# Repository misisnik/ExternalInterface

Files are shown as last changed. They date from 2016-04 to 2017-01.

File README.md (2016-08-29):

External user irnterface with usb
===================================
Project tags:
  - MCP2210
  - Displat with "IST3020"
  - Joystick
  - Python library

Project tree:
- hw
  - board with buttons on the left side - KiCad files - schematics and pcb
  - board with buttons next to joystick - KiCad files - schematics and pcb
  - casing - FreeCad projects for casing this user interface (3D pronting)
- sw
  - Python 3.4 project lib

It contains:
- [SW lib.](https://github.com/misisnik/ExternalInterface/tree/master/sw)
- [HW board 1](https://github.com/misisnik/ExternalInterface/tree/master/hw/board_buttons_next_to_joystick)
- [HW board 2](https://github.com/misisnik/ExternalInterface/tree/master/hw/board_buttons_on_the_other_side)
- [HW 3D casing](https://github.com/misisnik/ExternalInterface/tree/master/hw/casing)

Installation
------------
	-Ubuntu and python 2.7
	---------------
			$ apt-get update
			$ apt-get install python-dev
			$ apt-get install cython
			$ apt-get install libusb-1.0.0 libusb-1.0.0-dev libudev-dev
			$ pip install hidapi

		install Pillow
			$ apt-get install libjpeg-dev
			$ pip3 install pillow

		-- display LIB
		git clone https://github.com/misisnik/ExternalInterface

	-Raspbian Jesee
	---------------
			$ apt-get update
			$ sudo apt-get install git python3.4 python3-dev

		install pip3 from git
			$ git clone https://github.com/pypa/pip
			$ cd pip
			$ python3.4 setup.py install
			$ cd ..
			$ rm -r pip

		install cython
			$ apt-get install cython3

		libusb
			$ apt-get install libusb-1.0.0 libusb-1.0.0-dev libudev-dev

		install cython-hidapi
			$ git clone https://github.com/gbishop/cython-hidapi.git
			$ cd cython-hidapi
			$ python3 setup.py build
			$ python3 setup.py install
			$ cd ..
			$ rm -r cython-hidapi

		install Pillow
			$ apt-get install libjpeg-dev
			$ pip3 install pillow

		-- display LIB
		git clone https://github.com/misisnik/ExternalInterface

Examples
---------------

-[Main example - introduction of display + snake game](https://github.com/misisnik/ExternalInterface/blob/master/sw/example.py)

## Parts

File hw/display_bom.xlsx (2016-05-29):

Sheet: List1
Value | Seller | Part. No | Price [USD] | PC
2,2uF/10V | Farnell | 2496923 | 0.027 | 4
1uF/10V | Farnell | 2496916 | 0.017 | 8
0,1uF/25V | Farnell | 2496833 | 0.009 | 1
10nF/25V | Farnell | 2496827 | 0.009 | 1
4,7nF/ | Farnell | 1759098 | 0.016 | 1
1800pF | Farnell | 2524826 | 0.010 | 1
2200pF | Farnell | 2496845 | 0.008 | 1
2700pF | Farnell | 2524833 | 0.011 | 1
3300pF | Farnell | 2496853 | 0.007 | 1
3900pF | Farnell | 2524841 | 0.010 | 1
L-1334SRT | Farnell | 2001642 | 0.150 | 1
24R | Farnell | 2447310 | 0.004 | 1
390R | Farnell | 2447353 | 0.004 | 4
22K | Farnell | 9330828 | 0.001 | 1
33K | Farnell | 9331034 | 0.002 | 2
3K | Farnell | 9330976 | 0.001 | 1
10K | Farnell | 9330399 | 0.001 | 8
3K9 | Farnell | 9331140 | 0.002 | 1
68K | Farnell | 9331468 | 0.002 | 1
0R | Farnell | 2447743RL | 0.004 | 1
68R | Farnell | 9331484 | 0.002 | 2
1M | Farnell | 9330410 | 0.001 | 1
12MHz rez. | Farnell | 2470356 | 0.391 | 1
MIC5504-3,3 | Farnell | 2510377 | 0.097 | 1
LM239 | Farnell | 1564355 | 0.114 | 1
CD4532 | Farnell | 1739798 | 0.521 | 1
NPIC6C596ADJ | Farnell | 2445195 | 1.115 | 1
NE555 | Farnell | 9589880 | 0.314 | 1
USB typ B | Farnell | 1097897 | 0.754 | 1
ABT-405-RC PIEZO | Farnell | 1300024 | 1.303 | 1
MCP2210 | TME | MCP2210-I/SO | 1.897 | 1
PB6149L-3 | TME | PB6149L-3 | 0.850 | 2
192x64 px display + conn | buydisplay.com | ERC19264SBS-1 | 9.145 | 1
PCB | easyeda.com | Hasl, FR-4, 47x152mm | 4.215 | 1
Joystick | Ebay.com |  | 1.054 | 1
 |  | Total USD | 22.070

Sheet: List2
freq | cap
261 | 3.943703631e-08
294 | 3.501043019e-08
329 | 3.128591634e-08
349 | 2.949302715e-08
392 | 2.625782264e-08
440 | 2.33933329e-08
493 | 2.087843099e-08

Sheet: List4
0.649 | 0.0273608769
0.414 | 0.01745362563
0.204 | 0.008600337268
0.221 | 0.00931703204
0.389 | 0.01639966273
3.561 | 0.1501264755
0.102 | 0.004300168634
0.095 | 0.004005059022
0.033 | 0.001391231029
0.036 | 0.001517706577
0.033 | 0.001391231029
0.033 | 0.001391231029
0.044 | 0.001854974705
0.044 | 0.001854974705
0.091 | 0.003836424958
0.041 | 0.001728499157
0.033 | 0.001391231029
9.276 | 0.3910623946
2.311 | 0.09742833052
2.705 | 0.1140387858
12.368 | 0.5214165261
26.448 | 1.115008432
7.454 | 0.3142495784
17.889 | 0.7541736931
30.92 | 1.303541315
45 | 1.897133221
20.16 | 0.849915683
217 | 9.148397976
100 | 4.215851602
25 | 1.053962901

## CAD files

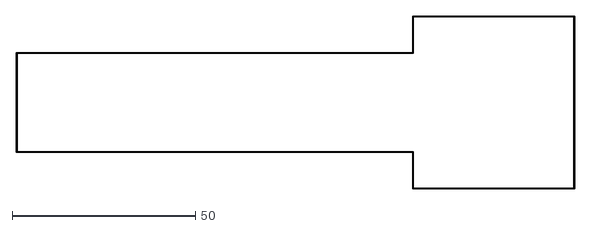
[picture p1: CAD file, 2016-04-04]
hw/board_buttons_on_the_other_side/rozhrani_semestralka-Edge_Cuts.dxf
152.1 x 47.1

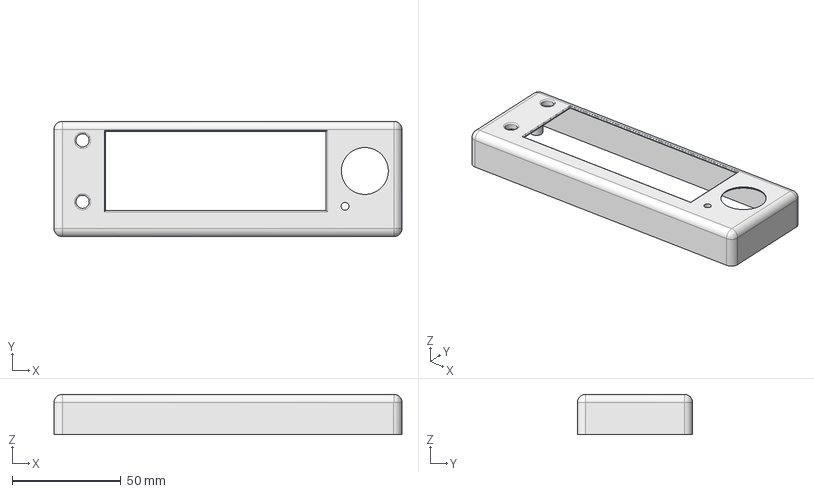
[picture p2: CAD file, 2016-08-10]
hw/casing 2/top_part.FCStd
160.0 x 53.0 x 18.5 mm

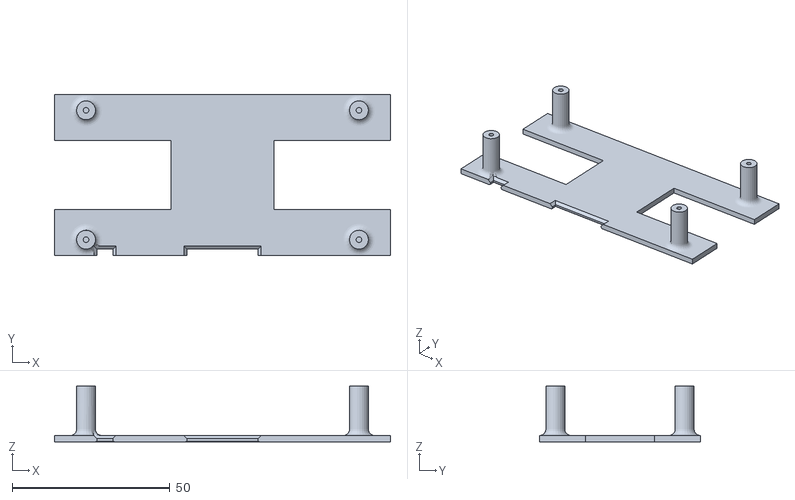
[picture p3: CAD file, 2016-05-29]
hw/casing/.stl format/table_part.stl
106.5 x 51.0 x 17.6

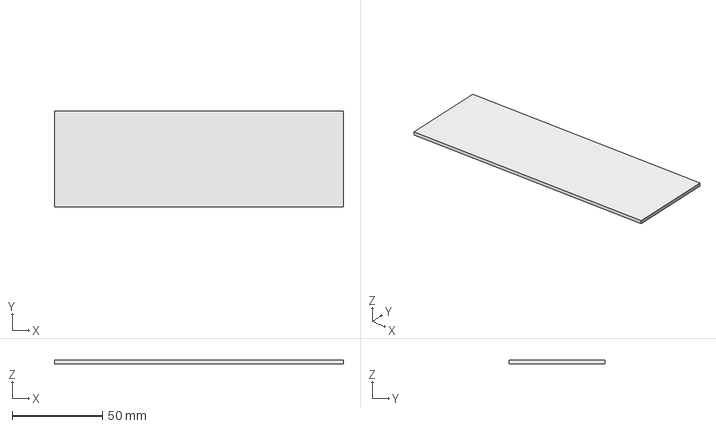
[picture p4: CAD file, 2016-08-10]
hw/casing 2/bottom_part.FCStd
160.0 x 53.0 x 2.00 mm

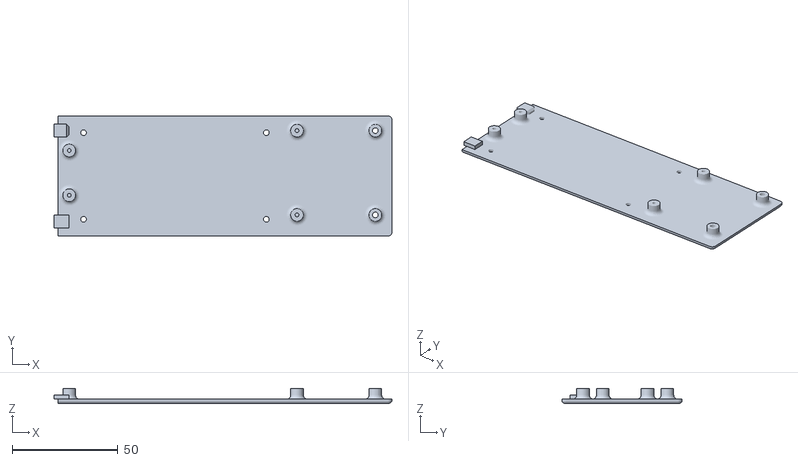
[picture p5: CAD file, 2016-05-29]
hw/casing/.stl format/bottom_part.stl
160.0 x 57.0 x 7.00

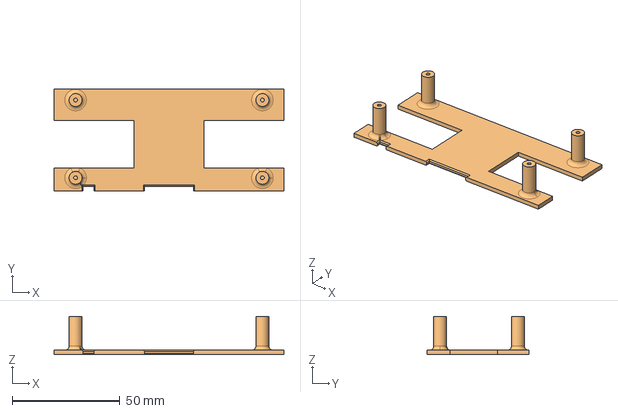
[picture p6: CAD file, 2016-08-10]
hw/casing 2/table_part.FCStd
106.5 x 47.0 x 17.6 mm
Fillet002 (Solid)

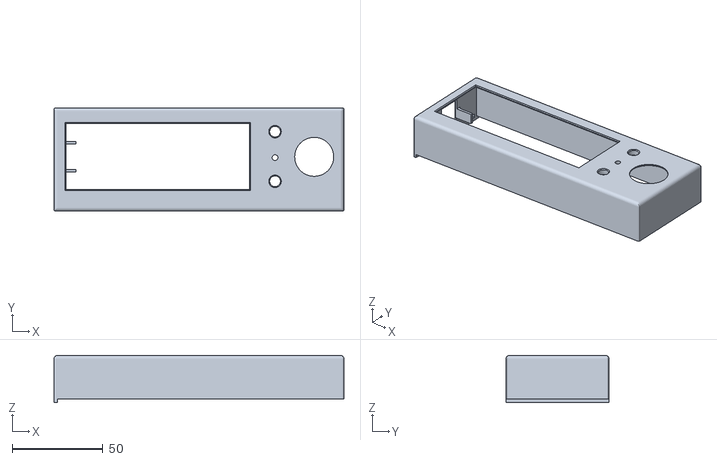
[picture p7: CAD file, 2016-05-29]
hw/casing/.stl format/top_part.stl
160.0 x 57.0 x 26.1

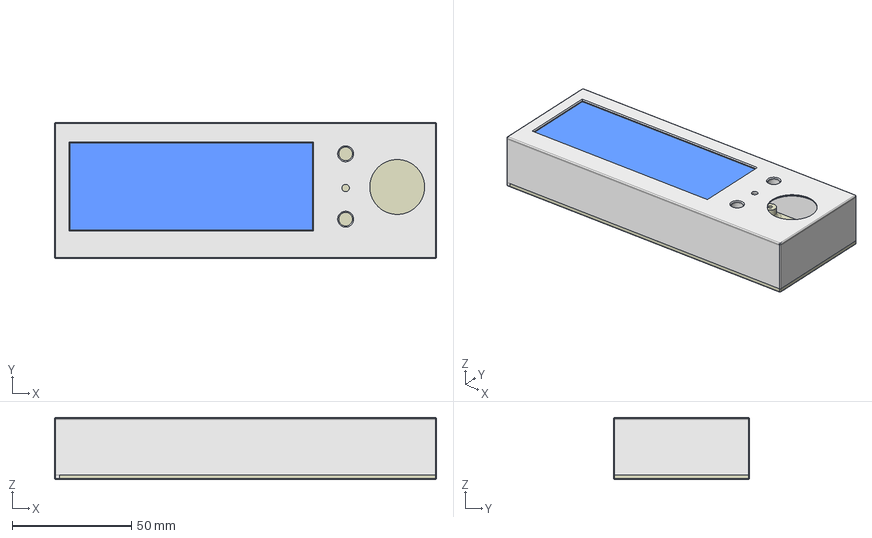
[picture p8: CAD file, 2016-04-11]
hw/casing/together.FCStd
160.0 x 57.0 x 26.1 mm
bottom
table
lcd
top

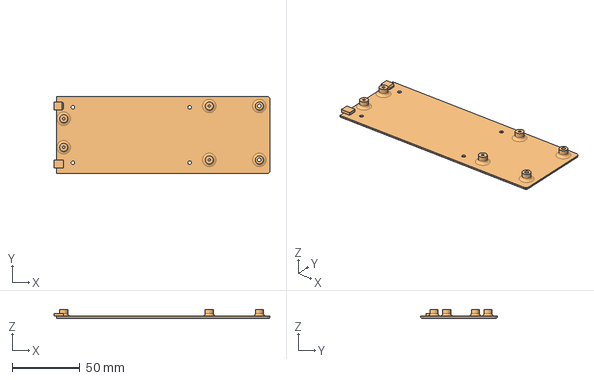
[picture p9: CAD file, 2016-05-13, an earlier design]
hw/casing/bottom_part.FCStd
160.0 x 57.0 x 7.00 mm
Fillet007 (Solid)

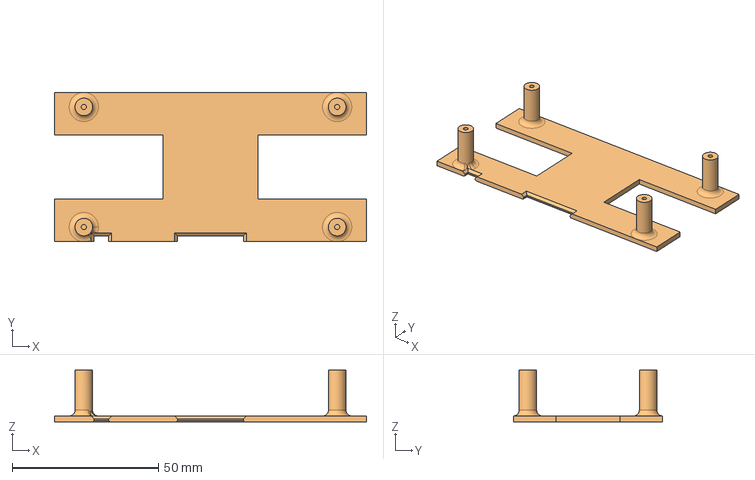
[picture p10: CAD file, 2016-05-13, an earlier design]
hw/casing/table_part.FCStd
106.5 x 51.0 x 17.6 mm
Fillet002 (Solid)

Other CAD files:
hw/casing/top_part.FCStd
hw/board_buttons_on_the_other_side/rozhrani_semestralka-F_Paste.dxf
hw/board_buttons_on_the_other_side/rozhrani_semestralka-F_SilkS.dxf

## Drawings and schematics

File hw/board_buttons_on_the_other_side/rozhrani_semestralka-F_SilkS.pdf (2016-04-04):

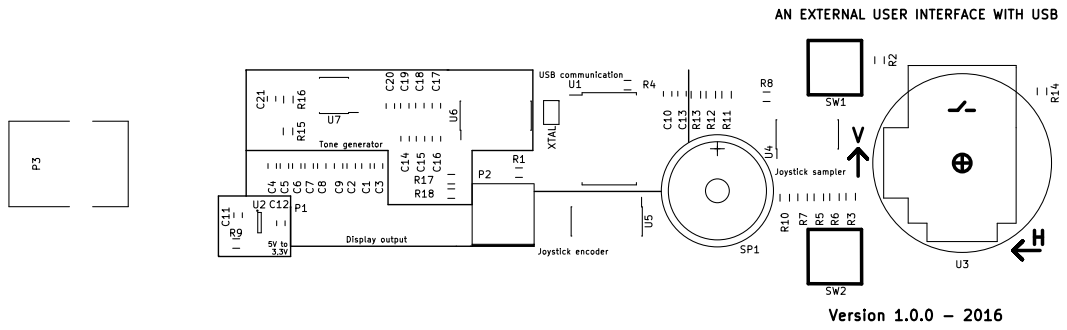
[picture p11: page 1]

Joystick encoder USB communication

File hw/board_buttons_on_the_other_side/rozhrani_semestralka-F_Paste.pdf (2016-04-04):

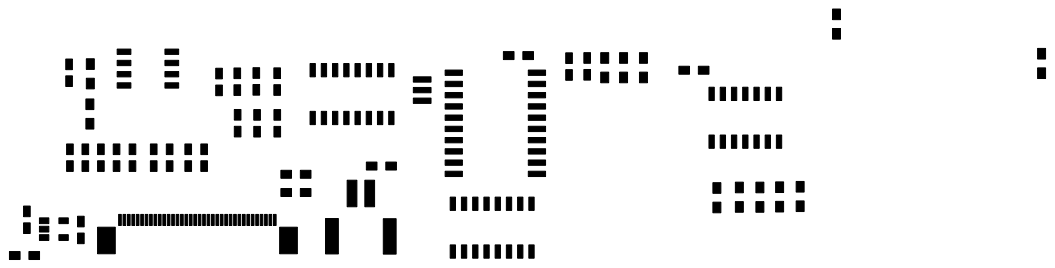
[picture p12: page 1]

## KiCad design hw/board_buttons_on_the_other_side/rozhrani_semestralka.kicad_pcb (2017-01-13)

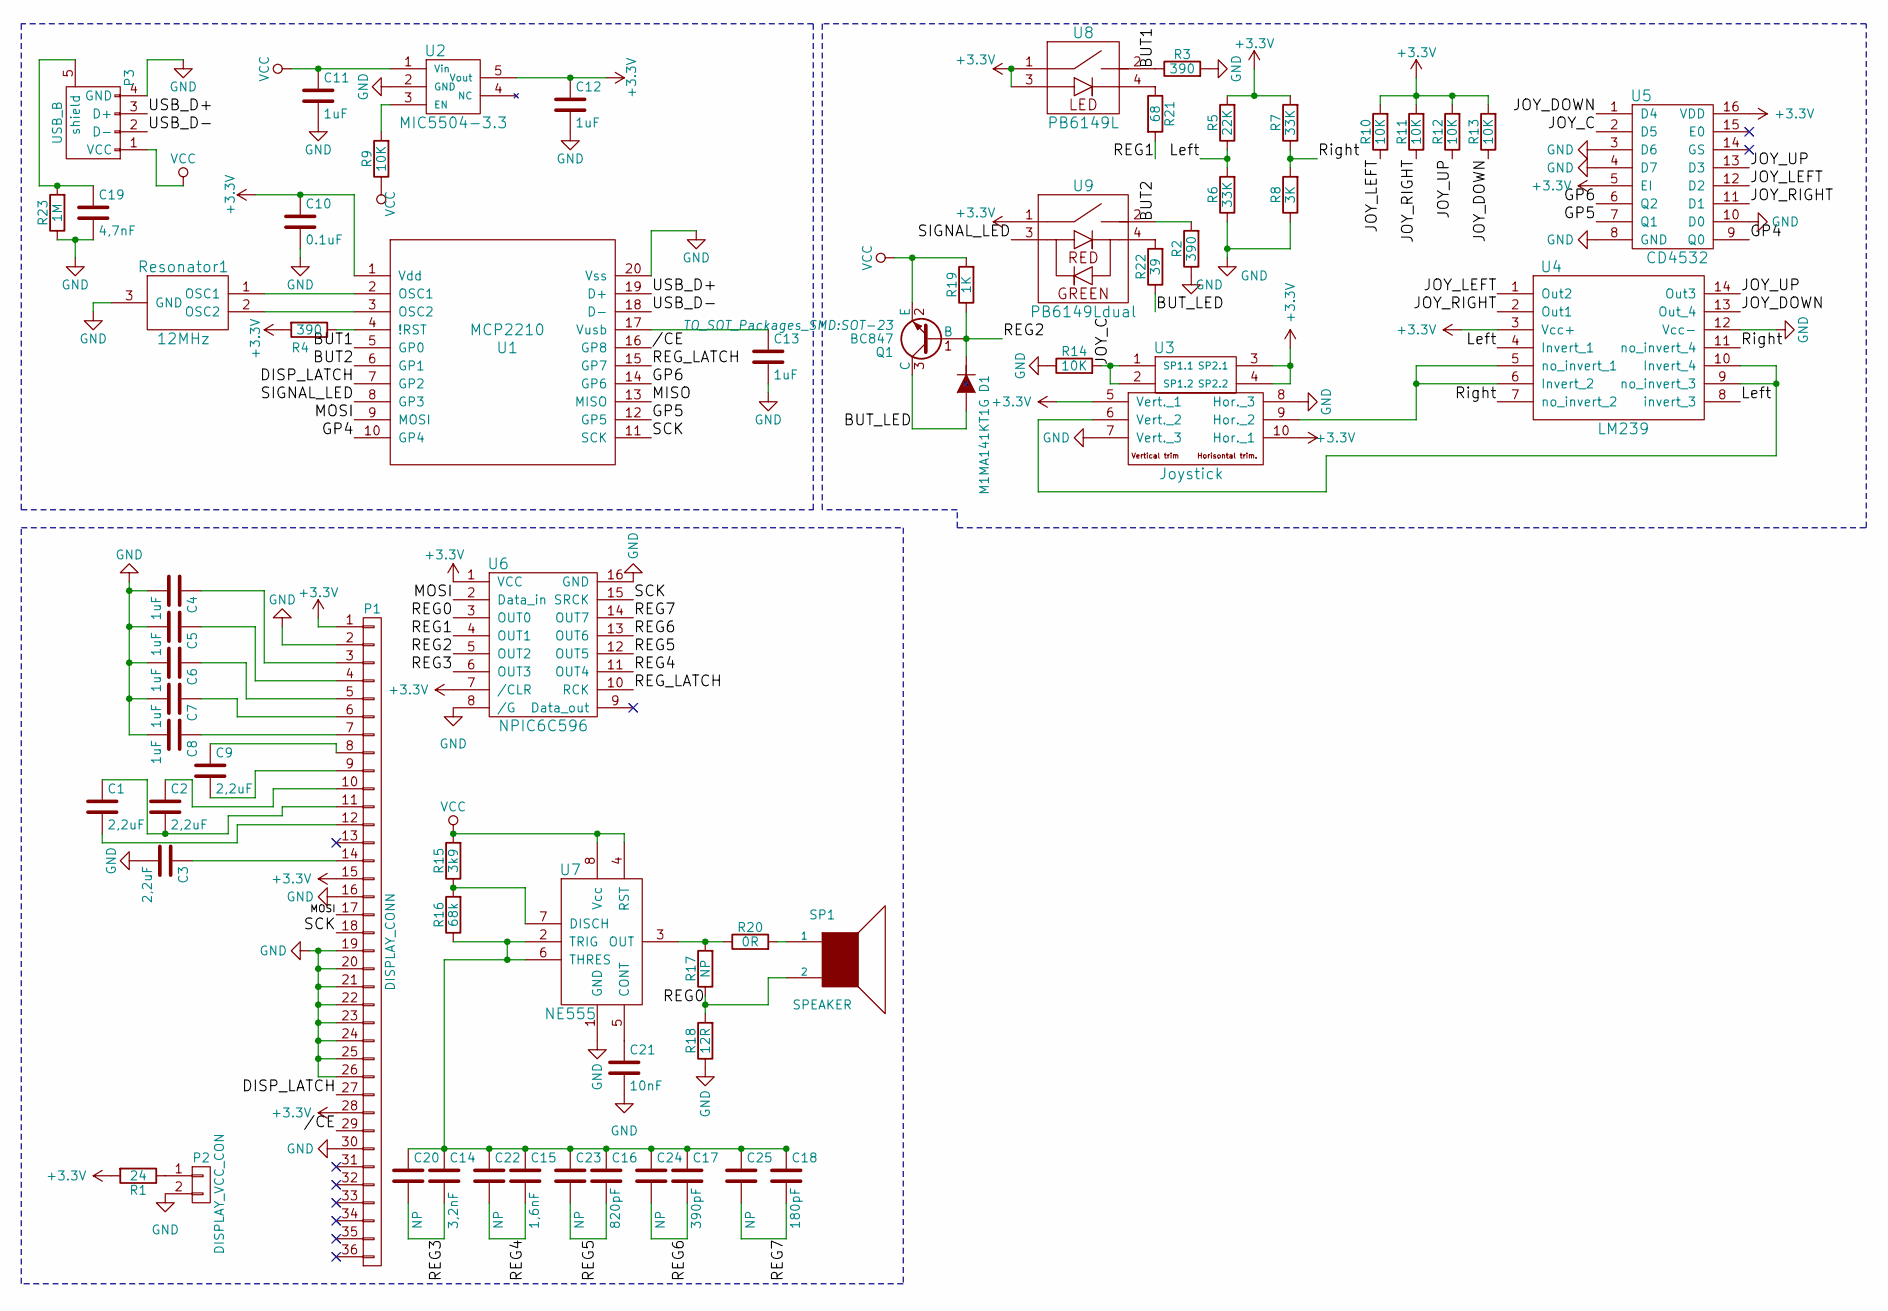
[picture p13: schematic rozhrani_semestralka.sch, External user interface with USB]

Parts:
C1, C2, C3, C9: 2,2uF; C_0603_HandSoldering
C4, C5, C6, C7, C8, C11, C12, C13: 1uF; C_0603_HandSoldering
C10: 0.1uF; C_0603_HandSoldering
C14: 3,2nF; C_0603_HandSoldering
C15: 1,6nF; C_0603_HandSoldering
C16: 820pF; C_0603_HandSoldering
C17: 390pF; C_0603_HandSoldering
C18: 180pF; C_0603_HandSoldering
C19: 4,7nF; C_0603_HandSoldering
C20, C22, C23, C24, C25: NP; C_0603_HandSoldering
C21: 10nF; C_0603_HandSoldering
D1: M1MA141KT1G; SOT-323
P1: DISPLAY_CONN; ZIF36
P2: DISPLAY_VCC_CON; disp_nap
P3: USB_B
Q1: BC847; SOT-23
R1: 24; R_0603_HandSoldering
R2, R3, R4: 390; R_0603_HandSoldering
R5: 22K; R_0603_HandSoldering
R6, R7: 33K; R_0603_HandSoldering
R8: 3K; R_0603_HandSoldering
R9, R10, R11, R12, R13, R14: 10K; R_0603_HandSoldering
R15: 3k9; R_0603_HandSoldering
R16: 68k; R_0603_HandSoldering
R17: NP; R_0603_HandSoldering
R18: 12R; R_0603_HandSoldering
R19: 1K; R_0603_HandSoldering
R20: 0R; R_0603_HandSoldering
R21: 68; R_0603_HandSoldering
R22: 39; R_0603_HandSoldering
R23: 1M; R_0603_HandSoldering
Resonator1: 12MHz; resonator12MHz
SP1: SPEAKER; Buzzer
U1: MCP2210; SOIC-20_7.5x12.8mm_Pitch1.27mm
U2: MIC5504-3.3; SOT-23-5
U3: Joystick
U4: LM239; SOIC-14_3.9x8.7mm_Pitch1.27mm
U5: CD4532; SOIC-16_3.9x9.9mm_Pitch1.27mm
U6: NPIC6C596; SOIC-16_3.9x9.9mm_Pitch1.27mm
U7: NE555; SOIC-8_3.9x4.9mm_Pitch1.27mm
U8: PB6149L
U9: PB6149Ldual; PB6149L

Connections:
+3V3: C10.1, C12.1, P1.1, P1.15, P1.28, R1.2, R4.2, R5.2, R7.2, R10.2, R11.2, R12.2, R13.2, U1.1 (Vdd), U2.5 (Vout), U3.3 (SP2.1), U3.4 (SP2.2), U3.5 (Vert._1), U3.10 (Hor._1), U4.3 (Vcc+), U5.5 (EI), U5.16 (VDD), U6.1 (VCC), U6.7 (/CLR), U8.1, U8.3, U9.1
//CE: P1.29, U1.16 (GP8)
/BUT1: R3.1, U1.5 (GP0), U8.2
/BUT2: R2.2, U1.6 (GP1), U9.2
/BUT_LED: D1.1 (A), Q1.3 (C), R22.1
/DISP_LATCH: P1.27, U1.7 (GP2)
/GP4: U1.10 (GP4), U5.9 (Q0)
/GP5: U1.12 (GP5), U5.7 (Q1)
/GP6: U1.14 (GP6), U5.6 (Q2)
/JOY_C: R14.2, U3.1 (SP1.1), U3.2 (SP1.2), U5.2 (D5)
/JOY_DOWN: R13.1, U4.13 (Out_4), U5.1 (D4)
/JOY_LEFT: R10.1, U4.1 (Out2), U5.12 (D2)
/JOY_RIGHT: R11.1, U4.2 (Out1), U5.11 (D1)
/JOY_UP: R12.1, U4.14 (Out3), U5.13 (D3)
/Left: R5.1, R6.2, U4.4 (Invert_1), U4.8 (invert_3)
/MISO: U1.13 (MISO)
/MOSI: P1.17, U1.9 (MOSI), U6.2 (Data_in)
/REG0: R17.1, R18.2, SP1.2, U6.3 (OUT0)
/REG1: R21.2, U6.4 (OUT1)
/REG2: D1.3 (K), Q1.1 (B), R19.1, U6.5 (OUT2)
/REG3: C14.2, C20.2, U6.6 (OUT3)
/REG4: C15.2, C22.2, U6.11 (OUT4)
/REG5: C16.2, C23.2, U6.12 (OUT5)
/REG6: C17.2, C24.2, U6.13 (OUT6)
/REG7: C18.2, C25.2, U6.14 (OUT7)
/REG_LATCH: U1.15 (GP7), U6.10 (RCK)
/Right: R7.1, R8.2, U4.7 (no_invert_2), U4.11 (no_invert_4)
/SCK: P1.18, U1.11 (SCK), U6.15 (SRCK)
/SIGNAL_LED: U1.8 (GP3), U9.3
/USB_D+: P3.3 (D+), U1.19 (D+)
/USB_D-: P3.2 (D-), U1.18 (D-)
GND: C3.2, C4.2, C5.2, C6.2, C7.2, C8.2, C10.2, C11.2, C12.2, C13.2, C19.2, C21.2, P1.2, P1.16, P1.19, P1.20, P1.21, P1.22, P1.23, P1.24, P1.25, P1.26, P1.30, P2.2, P3.4 (GND), R2.1, R3.2, R6.1, R8.1, R14.1, R18.1, R23.1, Resonator1.3 (GND), U1.20 (Vss), U2.2 (GND), U3.7 (Vert._3), U3.8 (Hor._3), U4.12 (Vcc-), U5.3 (D6), U5.4 (D7), U5.8 (GND), U5.10 (D0), U6.8 (/G), U6.16 (GND), U7.1 (GND); also elsewhere on the board
unnamed: C1.1, C2.2, P1.11
unnamed: C1.2, P1.12
unnamed: C2.1, P1.10
unnamed: C3.1, P1.14
unnamed: C4.1, P1.3
unnamed: C5.1, P1.4
unnamed: C6.1, P1.5
unnamed: C7.1, P1.6
unnamed: C8.1, P1.7
unnamed: C9.1, P1.8
unnamed: C9.2, P1.9
unnamed: C13.1, U1.17 (Vusb)
unnamed: C14.1, C15.1, C16.1, C17.1, C18.1, C20.1, C22.1, C23.1, C24.1, C25.1, R16.1, U7.2 (TRIG), U7.6 (THRES)
unnamed: C19.1, P3.5 (shield), R23.2
unnamed: C21.1, U7.5 (CONT)
unnamed: P2.1, R1.1
unnamed: R4.1, U1.4 (!RST)
unnamed: R9.2, U2.3 (EN)
unnamed: R15.1, R16.2, U7.7 (DISCH)
unnamed: R17.2, R20.1, U7.3 (OUT)
unnamed: R20.2, SP1.1
unnamed: R21.1, U8.4
unnamed: R22.2, U9.4
unnamed 63: Resonator1.1 (OSC1), U1.2 (OSC1); also elsewhere on the board
unnamed 64: Resonator1.2 (OSC2), U1.3 (OSC2); also elsewhere on the board
unnamed: U3.6 (Vert._2), U4.9 (no_invert_3), U4.10 (Invert_4)
unnamed: U3.9 (Hor._2), U4.5 (no_invert_1), U4.6 (Invert_2)
VCC: C11.1, P3.1 (VCC), Q1.2 (E), R9.1, R15.2, R19.2, U2.1 (Vin), U7.4 (RST), U7.8 (Vcc)

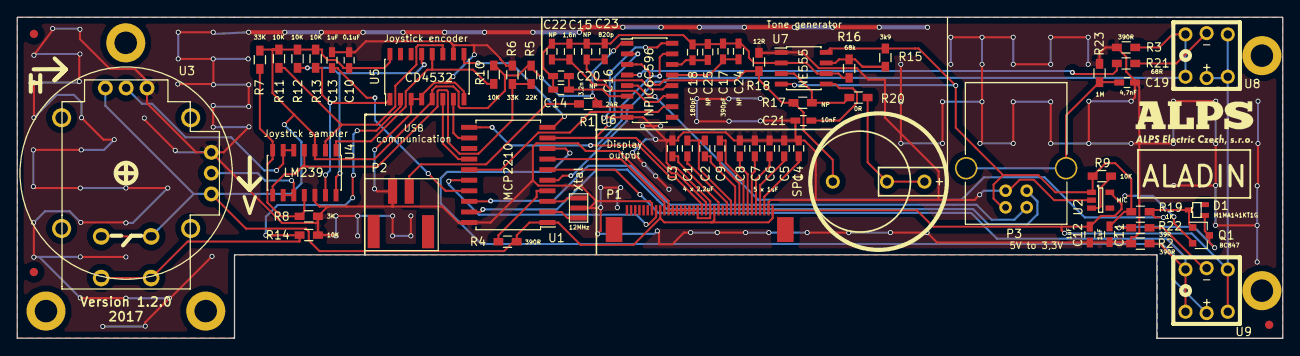
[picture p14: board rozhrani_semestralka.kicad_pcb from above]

Board: 2 copper layers, 152.0 x 38.6 mm, 67 parts (0 on the bottom side), 59 nets.

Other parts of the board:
FID1, FID2, FID3**: Fiducial_1mm_Dia_2.54mm_Outer_CopperTop
Xtal: 12MHz; resonator12MHz

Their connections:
GND: Xtal.3; also elsewhere on the board
unnamed 63: Xtal.1; also elsewhere on the board
unnamed 64: Xtal.2; also elsewhere on the board

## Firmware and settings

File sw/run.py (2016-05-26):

"""
display run
====================
.. moduleauthor:: Michal Sladecek <misisnik@gmail.com>
.. autoclass:: Display
.. autoclass:: Win
.. autofunction:: lib

"""
"""Top part of whole display software. There are mostly GUI commands"""

import os
import time

from controll import Controll
from matrix_orbital import MatrixOrbital
from window import GUI

class Win(object):
	"""
		class is under Display class
		main function of this class is creating and managing windows
		adding text and clear it
	"""
	def __init__(self, disp, win, opts):
		self.disp = disp
		self.win = win
		self.opts = opts

	def __set__(self, obj, value):
		"""
			in variable valus is text which has to show on display
		"""
		self.disp.font = self.opts['font']
		self.disp.text(value, [0, self.opts['rect'][0][1]], self.opts['alignment'][0], 1, 1)
		self.disp.rewrite()

	def clear(self):
		"""
			clear display
		"""
		self.disp.clearPartOfBuffer(self.opts['rect'], 0)
		self.disp.rewrite()

class Display(object):
	"""There are main library of display"""
	def __init__(self, orientation = 180):
		"""
			initialization for hw controll and gui part
		"""
		self.window = GUI(orientation)	#window degree
		self.defineWin()
		self.controll = Controll(self.window)
		#self.controll = MatrixOrbital(self.window, 'COM5')
		self.font = ['Arial', 10]
		#write on display first screen 
		self.rewrite()

	def defineWin(self):
		for win, opts in\
			[('main_win',   {'rect':      ((0, 0),  (192,64)),
				'font':      ['Arial', 10],
				'alignment': ('left', 'top')}),
			(	'status',     {'rect':      ((0, 0),  (192, 19)),
				'font':      ['Big', 12],
				'alignment': ('center', 'center')}),
			(	'message',    {'rect':      ((0, 20), (192, 44)),
				'font':      ['Arial', 10],
				'alignment': ('left', 'top')}),
			('error_win',  {'rect':      ((0, 45), (192, 64)),
			'font':      ['Tiny', 7],
			'alignment': ('left', 'top')})]:
			setattr(Display, win, Win(self, win, opts))

	def rotate(self, degree):
		"""
			rotate window
			input is just degree of rotating
		"""
		self.window.rotation = degree
		return True

	def rewrite(self):
		"""
			rewrite display from gui buffer
		"""
		return self.controll.RewriteDisplay()

	def resetBuffer(self):
		"""
			reset (erase) window (GUI) buffer
		"""
		return self.window.reset()

	def clearPartOfBuffer(self, position = [[0,0], [192, 64]], fill = False):
		"""
			clear part of buffer
				position - [[x0,y0], [x1,y1]]
		"""
		return self.window.clear(position)

	def reset(self):
		"""
			Reset display - it means that reset array in window (gui) and those write via SPI
		"""
		return self.control.Reset()

	def image(self, img, position = [0, 0], reverse = False):
		"""
			add image to window buffer
				img - path of file
				reverse - reverse image
		"""
		self.window.addImage(img, position, reverse)

	def text(self, text, position = [0, 0], align = 'left', spacing = 1, fill = 1):
		"""
			add text to screen buffer
				text - string of text
				position - [x, y]
				align - left, center, right
				spacing - how many pixels has between lines
				fill - 1 px is ON 0 px is OFF
			font u can set before this function by variable
			Display.font = ['Arial', 10] -> means font name and font size
			and return number of total text lines, printed text - to height
		"""
		return self.window.addMultilineText(text, self.font[1], position[0], position[1], align, self.font[0], spacing, fill)

	def lineText(self, text, position = [0, 0], align = 'left', fill = 1, align_parameter = 0):
		"""
			add just one line text
				text - string of text
				position - [x, y] where we can start write
				align - left, center, right
				fill - 1 is that px is ON, 0 is that px is OFF
			this function return width and height in pixels of text
				return (width, height)
			also as usually font u can change beore this function by variable
			Display.font = ['Arial', 10] -> means font name and font size
		"""
		return self.window.addText(text, self.font[1], position[0], position[1], align, self.font[0], fill, align_parameter)

	def rectangle(self, position, fill = True):
		"""
			add rectangle to screen buffer
				position - [[x0, y0], [x1, y1]]
				fill - True -> is filled px, False -> is doesn't filled just borderline has
		"""
		return self.window.addRectangle(position[0], position[1], fill)

	def arc(self, position, first, second, fill = 1):
		"""
			add part of ellipse
		"""
		return self.window.addArc(first, second, position[0], position[1], fill)

	def ellipse(self, position, fill = True):
		"""
			add ellipse to screen buffer
				position - [[x0, y0], [x1, y1]]
				fill - True -> is filled px, False -> is doesn't filled just borderline has
		"""
		return self.window.addEllipse(position[0], position[1], fill)

	def line(self, position, width = 1, fill = 1):
		"""
			add line to screen buffer
				position - [[x0, y0], [x1, y1]]
				width - width of line (basicly height :D)
				fill - 1 px is ON, 0 px is OFF
		"""
		return self.window.addLine(position[0], position[1], width, fill)

	def point(self, position, fill = 1):
		"""
			add point to screen buffer
				position - array of (x,y) like [(x,y), (x,y), (x,y)] each point is just 1px width
				fill - 1 px is ON, 0 px is OFF
		"""
		return self.window.addPoint(position, fill)

	def textSize(self, text):
		"""
			this function returned width and height of text size in px
			example call: width, height = Display.textSize() ----- function return "(width, height)"
			font u can edit before this function by variable font -> Display.font = ["font name", font size in px]
		"""
		return self.window.getMultilineTextSize(text, self.font[1], self.font[0])

	def textLineSize(self, text):
		"""
			this function returned width and height of just one line of text in px
			return (width, height)
		"""
		return self.window.getTextSize(text, self.font[1], self.font[0])

	def joystick(self):
		"""
			this function maintenance of joystick
			return is: up, down, left, right, or center
		"""
		return self.controll.Joystick()

	def buttons(self):
		"""
			this function case of 2 buttons OK and NG
		"""
		return self.controll.Buttons()

	def readyButtons(self, data, s = '1'):
		"""
			this function trigger LED in OK and NG button
				data - 'OK' for ok, 'NG' for NG and 'BOTH' for BOTH
		"""
		if not s: s = '0'
		if data == 'OK':
			self.controll.shift_register[3] = s
		elif data == 'NG':
			self.controll.shift_register[2] = s
		elif data == 'BOTH':
			self.controll.shift_register[2] = s
			self.controll.shift_register[3] = s

		self.controll.SetShiftRegister()

	def sound(self, data):
		"""
			this function trigger BUZZER
		"""
		if data == 'a':
			self.controll.shift_register[4] = '1'
			self.controll.shift_register[5] = '0'
			self.controll.shift_register[6] = '0'
			self.controll.shift_register[7] = '0'
		elif data == 'b':
			self.controll.shift_register[4] = '0'
			self.controll.shift_register[5] = '1'
			self.controll.shift_register[6] = '0'
			self.controll.shift_register[7] = '0'
		elif data == 'c':
			self.controll.shift_register[4] = '0'
			self.controll.shift_register[5] = '0'
			self.controll.shift_register[6] = '1'
			self.controll.shift_register[7] = '0'
		elif data == 'd':
			self.controll.shift_register[4] = '0'
			self.controll.shift_register[5] = '0'
			self.controll.shift_register[6] = '0'
			self.controll.shift_register[7] = '1'
		else:
			self.controll.shift_register[4] = '0'
			self.controll.shift_register[5] = '0'
			self.controll.shift_register[6] = '0'
			self.controll.shift_register[7] = '0'
		self.controll.SetShiftRegister()


	def led(self, status):
		"""
			this function care about led
				status - True or False
		"""
		return self.controll.setErrorLed(status)

	def title(self, title):
		"""
			add title to function
				title - title text
		"""
		self.font = ['Arial', 10]
		title_width, title_height = self.lineText(title, [0, 0], 'center')
		self.line([[0,title_height + 2], [self.window.display_width, title_height + 2]], 2)

	def menu(self, title, data):
		"""
			Menu function - create menu part
			inputs are:
				- string of menu item
				- array with menu items like ['item 1', 'item 2', 'item 3']
			function jus return key of choosen menu items
		"""
		#set font for menu
		self.font = ['Arial', 10]

		#variables
		menu_selected = 0		#selected imtem in menu
		while 1:
			counter = 0
			menu_count = 0			#actual
			#add menu title and underline 2x
			self.title(title)
			#helper
			if menu_selected > len(data) - 1 :
				menu_selected = len(data) -1
			if menu_selected < 2:
				counter = 0
			elif menu_selected > len(data) - 2 :
				counter = menu_selected - 2
			else:
				counter = menu_selected - 1
			#draw data on menu list
			for m in range(0,3): #just 3 files per page
				try:
					if menu_selected < 2:
						item = data[m]
					elif menu_selected > len(data) - 2:
						item = data[menu_selected -2  + m]
					else:
						item = data[menu_selected -1  + m]
				except:
					#end of line - exception - no more menu :D
					break
				#and finally create menu
				fill = True
				if menu_selected == counter:
					w,h = self.textLineSize(item)	#get size of item
					fill = False
					#add background rectangle
					self.rectangle([[0, 20+(menu_count*12)], [self.window.display_width, 20+(menu_count*12)+(h+1)]])

				#add text which could be multiline
				self.text(item, [0, 20+(menu_count*12)], 'center', 1, fill)
				counter += 1
				menu_count += 1
			self.rewrite()
			#get joystick seting
			joystick_old = self.joystick()
			while 1:
				new_joystick = self.joystick()
				if joystick_old != new_joystick or new_joystick:
					break
				#time.sleep(0.1)
			#joystick setting
			if new_joystick == 'up':
				menu_selected -= 1
			elif new_joystick == 'down':
				menu_selected +=1
			elif new_joystick == 'center':
				return menu_selected	#return choosed item...
			#finally check selected menu
			if menu_selected >= len(data):
				menu_selected = len(data) - 1
			elif menu_selected < 0:
				menu_selected = 0
			#and reset window -> erase window in GUI part
			self.resetBuffer()

	def textArea(self, text, position = [0, 0], align = "left", percent_style = False):
		"""
			Create text area into gui buffer -> it can be more pages, and its remote by joystick
				text - multiline text string
				position - [x, y]
				align - left, center, right
		"""
		self.readyButtons('BOTH')
		printed_text = text
		per_page = 0
		text_array  = []
		c = 0
		while 1:
			self.resetBuffer()
			lines, printed_lines, printed = self.text(printed_text, [0, 0], 'center')

			if text_array == []:
				text_array = printed
				per_page = printed_lines

			#print line
			self.rectangle([[0,59],[192,63]], False)
			#filling
			if percent_style:
				self.rectangle([[-1,60], [int((192/len(text_array))*(c + printed_lines)), 62]])
			else:
				self.rectangle([[int((192/len(text_array))*c), 60], [int((192/len(text_array))*(c + printed_lines)), 62]])
			self.rewrite()

			#parse new text 
			while 1:
				joy = self.joystick()
				#can down
				if self.buttons() == 'BOTH':
					return self.readyButtons('BOTH', False)
				if (c + printed_lines) < len(text_array):
					if joy == 'down' or joy == "right":
						c += printed_lines
						break
				#can up
				if c > 0:
					if joy == 'up' or joy == "left":
						c -= printed_lines
						if c < 0:
							c = 0
						break
				time.sleep(0.1)
			printed_text = " ".join(text_array[c: c + per_page])

	def selectNumber(self, title, start, step):
		"""
			selecting number from x step is step
				from
				step
			returned value of choosen number
		"""
		choosen = start
		while 1:
			self.resetBuffer()
			self.title(title)
			self.rectangle([[71, 20], [121, 55]])
			rectangle_width = 50

			win = (192 - rectangle_width) / 2
			#and two lines
			self.line([[0,29],[192 ,29]], 2)
			self.line([[0,45],[192 ,45]], 2)
			self.line([[win / 2,29],[win / 2 ,45]], 1)
			self.line([[win + rectangle_width + (win /2 ),29],[win + rectangle_width + (win / 2) ,45]], 1)

			self.font = ['Arial', 7]
			self.lineText(str('-{0}'.format(int(10/step) * step)), [0, 13], "center")
			self.lineText(str('+{0}'.format(int(10/step) * step)), [0, 56], "center")

			#show choosen 
			self.font = ['Arial', 17]
			choosen_width, choosen_height = self.lineText(str(choosen), [0,29], "center", 0)
			self.font = ['Arial', 10]

			count = 0
			for i in range(choosen - (2 * (step)), choosen + (step * 6), step):
				if choosen == i or i < 0 :
					continue
				tw, th = self.textLineSize(str(i))
				if i < choosen:
					if (i + step) != choosen:
						#first
						pos = ((win / 2) / 2) - (tw / 2)
					else:
						#second
						pos = (win/2) + 2 + ((win / 2) / 2) - (tw / 2)
				else:
					count +=1
					if (i - step) == choosen:
						#next one - after choosen
						pos = win + rectangle_width + 2 + ((win / 2) / 2) - (tw / 2)
					else:
						#second
						pos = win + rectangle_width + (win/2) + 2 + ((win / 2) / 2) - (tw / 2)
				self.lineText(str(i), [pos, 33])
				if count == 2:
					break
			self.rewrite()

			#joystick
			while 1:
				joy = self.joystick()
				if joy == "center":
					return choosen
				elif joy == "left" and choosen > start:
					choosen -= step
					break
				elif joy == "right":
					choosen += step
					break
				elif joy == "up" and choosen > 10:
					choosen -= int(10/step) * step
					break
				elif joy == "down":
					choosen += int(10/step) * step
					break
				time.sleep(0.005)

	def selectNumber2(self, title, start, step):
		"""
			selecting number 2 format -  from x step is step
				from
				step
			returned value of choosen number
		"""
		choosen = start
		while 1:
			self.resetBuffer()

			self.rectangle([[116, 17], [166, 48]])

			self.rectangle([[122, 0], [160, 18]], 0)
			self.rectangle([[122, 47], [160, 63]], 0)
			self.rectangle([[90, 20], [117, 45]], 0)
			self.rectangle([[165, 20], [191, 45]], 0)

			#and two lines
			self.font = ['Arial', 15]
			self.lineText('Select \nnumber', [0, 15], "left")
			self.font = ['Arial', 10]
			self.lineText(str('-{0}'.format(int(10/step) * step)), [0, 5], "center", align_parameter = 45)
			self.lineText(str('+{0}'.format(int(10/step) * step)), [0, 50], "center", align_parameter = 45)
			self.lineText(str('-{0}'.format(step)), [0, 27], "center", align_parameter = 10)
			self.lineText(str('+{0}'.format(step)), [0, 27], "right", align_parameter = -6)
			#show choosen 
			self.font = ['Arial', 17]
			choosen_width, choosen_height = self.lineText(str(choosen), [0,25], "center", 0, align_parameter = 45)
			self.font = ['Arial', 10]

			count = 0

			self.rewrite()

			#joystick
			while 1:
				joy = self.joystick()
				if joy == "center":
					return choosen
				elif joy == "left" and choosen > start:
					choosen -= step
					break
				elif joy == "right":
					choosen += step
					break
				elif joy == "up" and choosen > 10:
					choosen -= int(10/step) * step
					break
				elif joy == "down":
					choosen += int(10/step) * step
					break
				time.sleep(0.005)

	def question(self, text):
		"""
			add function to rendering question on display
				text - question text
			return is True when answer is OK or False when answer is NG
		"""
		self.resetBuffer()
		self.font = ['Arial', 11]
		question_width, question_height = self.lineText(text, [3, 25])

		self.font = ['Arial', 12]
		#button OK
		self.rectangle([[150,0],[192,20]], False)
		self.rectangle([[153,3],[192,17]], False)
		self.line([[150,0],[153,3]], 1)
		self.line([[150,20],[153,17]], 1)

		self.lineText('OK', [164, 4])
		#button NG
		self.rectangle([[150,43],[192,63]], False)
		self.rectangle([[153,46],[192,60]], False)
		self.line([[150,43],[153,46]], 1)
		self.line([[150,63],[153,60]], 1)
		self.lineText('NG', [164, 47])
		self.rewrite()

		#set buttons
		self.readyButtons('BOTH')
		while 1:
			#load buttons and w8 for push OK or NG
			buttons = self.buttons()
			if buttons in ['OK', 'NG']:
				self.readyButtons('BOTH', False)
				return buttons
			time.sleep(0.1)

	def checkbox(self, title, data):
		"""
			add checkboxs from data
			data - array of checkbox example: ['Question 1', 'Question 2', 'Question 3']
			return array of true or false example [True, False, False]....
			press center button to send
		"""
		position = 0
		page = 0
		self.readyButtons('OK')
		data_result = [False] * len(data)
		while 1:
			self.resetBuffer()
			self.title(title)
			self.textSize =  ['Arial', 10]

			for i in range(3):
				if position + i > len(data):
					break
				p = (i * 12)
				actual = int(position -1/3) + i
				if position - 1 < len(data) and position > 0 and i == 1:
					self.rectangle([[-1, 18 + p], [192, 28 + p]], False)
				elif position == 0 and i == 0:
					self.rectangle([[-1, 18 + p], [192, 28 + p]], False)

				#checkbox
				self.rectangle([[1,20 + p], [7,26 + p]], False)
				self.lineText(data[actual], [9,17 + p])
				#checked
				if data_result[actual] == True:
					self.line([[1,20 + p], [7,26 + p]], 1)
					self.line([[7,20 + p], [1,26 + p]], 1)
			self.rewrite()
			#joystick
			while 1:
				if self.buttons() == 'OK':
					self.readyButtons('OK', False)
					return data_result
				joy = self.joystick()
				if joy == 'up' and position > 0:
					position -= 1
				elif joy == 'down' and position + 1 < len(data):
					position += 1
				elif joy == 'center':
					data_result[position] = not data_result[position]
				else:
					time.sleep(0.1)
					continue
				break

	def circleLoader(self, title,  fill = 0):
		"""
			widget for circle circleLoader
				title - title
				fill - percent of filling
		"""
		pos = [129,0]
		self.resetBuffer()
		self.ellipse([[pos[0] + 0, 0], [pos[0] + 63, 63]], 0)
		self.ellipse([[pos[0] + 5, 5], [pos[0] + 58, 58]], 0)

		show = ((fill * 360)/100) - 90
		self.arc([[pos[0] + 2, 2], [pos[0] + 61, 61]], -90, show, 1)
		self.arc([[pos[0] + 3, 3], [pos[0] + 60, 60]], -90, show, 1)

		self.font = ['Arial', 20]
		self.lineText("{0}%".format(fill), [0, 20], "center", align_parameter = 66)

		self.lineText(title, [0, 20], "left")

		self.rewrite()

	def rectangleLoader(self, title, fill = 0):
		"""
			widget for rectangle loader
				title - title
				fill - percent of filling
		"""
		self.resetBuffer()
		self.title(title)
		self.rectangle([[3,40],[188,60]], 0)
		show = ((fill * 183)/100)
		self.rectangle([[4,41],[show+4,59]], 1)
		self.font = ['Arial', 10]
		self.lineText("{0}%".format(fill), [0, 26], 'center')
		self.rewrite()

	def quantity(self, title, pieces, done = 0, percent_line = True):
		"""
			widget for revew quantity blocks
				pieces - how manny pieces are in line
				done - how many pieces is filled (done)
				percent_line - show recangle in percent line
		"""
		if done>pieces:
			return False
		self.resetBuffer()
		self.title(title)
		self.rectangle([[-1,40],[192,60]], 0)

		self.font = ['Arial', 17]
		self.lineText("{0}/{1}".format(done,pieces), [0, 20], "center")

		if percent_line:
			pos = int((((done * 100)/pieces)/100)*192)
			self.rectangle([[0, 41],[pos,59]], 1)
		piece = int(192/pieces)
		for i in range(done):
			self.rectangle([[(i*piece),41],[(i*piece) + piece, 59]], 1)
		self.rewrite()

	def test(self):
		"""
			just main part of this class - usually add text and so on.... for testing
		"""
		self.readyButtons('BOTH')
		while 1:
			for i in range(ord('a'), ord('d')):
				self.sound(chr(i))
				time.sleep(0.1)
			if self.buttons() == 'BOTH':
				self.sound(False)
				break
		self.readyButtons('BOTH', False)
		self.window.addImage()
		self.rewrite()
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

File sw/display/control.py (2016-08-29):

"""
display control
====================
.. moduleauthor:: Michal Sladecek <misisnik@gmail.com>
.. autoclass:: Control
.. autofunction:: lib

"""
from .mcp import MCP2210
import numbers
import time
############################################
#main class
############################################
class Control(object):
	def __init__(self, gui, register = ['0'] * 8):
		"""
			Authenticate and inicialization display for fast useing
		"""

		#display buffer
		self.display_buffer = [''] * 1536
		#spi buffer
		self.spi_buffer = ''
		#register buffer
		self.shift_register = register
		#reverse display variable
		self.reverse = False
		#last dc (latch) for display
		self.last_display_dc = False
		#first ve have to inicialization mcp2210
		self.init_mcp2210()
		#set shift register
		self.SetShiftRegister()
		#next is display ist3020 inicialization
		self.init_display()
		#gui
		self.gui = gui

	def init_mcp2210(self):
		"""inicialization of MCP2210 main chip which allow communication from system to display"""
		#self.communication = MCP2210(0x04D8, 0x00DE)
		try:
			self.communication = MCP2210(0x04D8, 0x00DE)
		except Exception as e:
			raise Exception('Failed to open USB chanel')

		#gpio local variables
		self._gpio = self.communication.gpio
		self._gpio_direction = self.communication.gpio_direction
		#other inicialization
		self.gpio_init()
		self.spi_init()



	def gpio_init(self):
		"""
			GPIO designations 	- 0x00 is GPIO, 0x01 is Chip selects, 0x02 is Dedicated function pin
			GPIO direction 		- 0x00 is Output, 0x01 is Input
		"""
		#designation
		gpio_settings = self.communication.chip_settings
		gpio_settings.pin_designations[0] = 0x00
		gpio_settings.pin_designations[1] = 0x00
		gpio_settings.pin_designations[2] = 0x00
		gpio_settings.pin_designations[3] = 0x01
		gpio_settings.pin_designations[4] = 0x00
		gpio_settings.pin_designations[5] = 0x00
		gpio_settings.pin_designations[6] = 0x00
		gpio_settings.pin_designations[7] = 0x00
		gpio_settings.pin_designations[8] = 0x00
		self.communication.chip_settings = gpio_settings
		#and also direction
		for i in range(0,9):
			if i == 0 or i == 1 or i == 4 or i == 5 or i == 6:
				self._gpio_direction[i] = 0x01
			else:
				self._gpio_direction[i] = 0x00
				self._gpio[i] = False

	def spi_init(self):
		"""
			SPI inicialization
		"""
		spi_settings = self.communication.transfer_settings
		spi_settings.bit_rate = 10000000
		spi_settings.idle_cs = 0b000001000		#idle of CE pins 0-8
		spi_settings.active_cs = 0b000000000	#active of CE pins 0-8
		spi_settings.spi_mode = 0x00 			#SPI mode could be 0x00, 0x01, 0x02
		spi_settings.interbyte_delay = 0
		spi_settings.cs_data_delay = 0
		spi_settings.lb_cs_delay = 0
		self.communication.transfer_settings = spi_settings

	def init_display(self):
		"""
			Inicialization of ist3020 display
		"""
		self.WriteCommand(0xE2, True)	#Sw reset
		time.sleep(0.01)
		self.WriteCommand(0xab)			#Built-in Oscillator ON
		self.WriteCommand(0xa0)			#s1-s132    
		self.WriteCommand(0xc8)			#c64-c1
		self.WriteCommand(0xa2)			#1/9bias
		self.WriteCommand(0x2c)			#VC ON
		self.WriteFromBuffer()		#Finally write whole packet from SPI buffer
		time.sleep(0.01)
		self.WriteCommand(0x2e, True)	#VR ON - fast write command
		time.sleep(0.01)
		self.WriteCommand(0x2f, True)	#VF ON - fast write command
		time.sleep(0.01)
		self.WriteCommand(0x20)			#Regulor_Resistor_Select
		self.WriteCommand(0x81)			#Set Reference Voltage Select Mode
		self.WriteCommand(45)			#Set Reference Voltage Register
		self.WriteCommand(0x70)			#External capacitor
		self.WriteCommand(0x40)			#Set start line
		self.WriteCommand(0xaf)			#Display on
		self.WriteCommand(0x90)
		self.WriteCommand(0x00)
		self.WriteCommand(0xa6)
		self.WriteCommand(0xa4)
		self.WriteFromBuffer()			#Finally write whole packet from SPI buffer


	def WriteCommand(self, data, fast = False):
		"""
			Write commands data to ist3020 display
			if variable fast is True then the data going to send without buffering
		"""
		#Set DC low for command
		if self.last_display_dc != False:
			self._gpio[2] = False
			self.last_display_dc = False
		#Convert scalar argument to list so either can be passed as parameter.
		if isinstance(data, numbers.Number):
			data = [data & 0xFF]
		#sending data
		self.WriteByte([chr(x) for x in data], fast)

	def WriteData(self, data, fast = False):
		"""
			Write data to ist3020 display
			if variable fast is True then the data going to send without buffering
		"""
		# Set DC low for command, high for data.
		if self.last_display_dc != True:
			self._gpio[2] = True
			self.last_display_dc = True
		# Convert scalar argument to list so either can be passed as parameter.
		if isinstance(data, numbers.Number):
			data = [data & 0xFF]
		#sending data
		self.WriteByte([chr(x) for x in data], fast)

	def WriteByte(self, data, fast = False):
		"""
			If variable fast is True then send now (without buffering) else buffering data until called funtion WriteFromBuffer
		"""
		if fast:
			try:
				self.communication.transfer("".join(data))
			except ValueError as e:
				self.exceptionConnect()
				time.sleep(0.5)
				#and try again
				self.WriteByte(data, fast)

		else:
			self.spi_buffer += "".join(data)

	def WriteFromBuffer(self):
		"""
			Write data from buffer
		"""
		try:
			self.communication.transfer(self.spi_buffer)
		except ValueError as e:
			self.exceptionConnect()
			time.sleep(0.5)
			#and try again
			self.WriteFromBuffer()

		self.spi_buffer = ''

	def SetPageAddress(self, data):
		"""
			Set page address of 192x64px display -> in ist3020
		"""
		address=0xb0|data
		self.WriteCommand(address)

	def SetColumnAddress(self, data):
		"""
			Set column address of 192x64px display -> in ist3020
		"""
		self.WriteCommand((0x10|(data>>4)))
		self.WriteCommand((0x0f&data))

	def RewriteDisplay(self):
		"""
			Rewrite display from buffer
			There are rewrite just not equals segments

			The display has 8 pages each is one write from buffer
		"""
		if self.gui.changed:
			self.gui.getBitmap()	#get new bitmap of gui
			self.gui.changed = False

		picture = self.gui.data[::-1]
		#dooo
		for i in range(0, 0x08):
			#compare page with buffer
			if self.display_buffer[i*192:i*192+192] == picture[i*192:i*192+192]:
				continue
			#compare columns with buffer
			start = 0
			end = 192
			for c in range(192):
				if picture[i*192+c] != self.display_buffer[i*192+c] and start == 0:
					start = c
				if picture[i*192+c:i*192+192] == self.display_buffer[i*192+c:i*192+192]:
					end = c
				break
			#and finally we can describe page and column
			self.SetPageAddress(i)
			self.SetColumnAddress(start)
			self.WriteFromBuffer()		#write packet from buffer
			self.WriteData(picture[i*192+start:i*192+end])
			self.WriteFromBuffer()		#write packet from buffer
		#and rewrite buffer
		self.picture_buffer = picture

	def Reset(self):
		"""
			reset picture on display + reset picture on gui buffer
		"""
		self.gui.reset()
		self.control.RewriteDisplay()
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

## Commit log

2016-04-04 First commit - create project repository
    [bottom_part.FCStd, bottom_part.stl, rozhrani_semestralka-Edge_Cuts.dxf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]
2016-04-06 Setup demo and repaired bugs and mistakes...
    [controll.py, run.py, window.py]
2016-04-06 Prepare main class Display - now can someone juts know only this class to woork with display - also rework menu
    [run.py, window.py]
2016-04-08 Add bom to HW part, create function textArea for big texts
2016-04-08 Upgrade value of resitors neer to joystick + added bom
    [display_bom.xlsx, rozhrani_semestralka.sch]
2016-04-08 Setup new board - changed from test board configuration
2016-04-08 Error LED diode function
    [controll.py, run.py]
2016-04-11 Added checkbox and Question except control via buttons OK and NG
2016-04-11 Change holes to another buttons
    [together.FCStd, top_part.FCStd]
2016-04-11 Sorting schematic parts
    [rozhrani_semestralka.sch]
2016-04-12 just updated schematic package in NPIC6C596
    [rozhrani_semestralka.sch]
2016-04-20 Added buttons - OK and NG
2016-04-20 Added buttons light - LED under buttons OK and NG
2016-04-25 Added hw board version 1.0.0 - buttons to another side and small updates
    [rozhrani_semestralka.kicad_pcb, rozhrani_semestralka.sch]
2016-04-29 missing disable underlight of buttons
    [run.py]
2016-04-29 The device support of linux distribution
2016-05-11 Separate two different PCB - just 2 KiCad projects - buttons on left side or buttons next to joystick
    [display_bom.xlsx, rozhrani_semestralka-Edge_Cuts.dxf, rozhrani_semestralka-F_Paste.dxf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]
2016-05-11 Deleted old files
    [rozhrani_semestralka-Edge_Cuts.dxf, rozhrani_semestralka-F_Paste.dxf, rozhrani_semestralka-F_SilkS.dxf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]
2016-05-11 Updated display bom
    [display_bom.xlsx]
2016-05-11 Reduced board size and replace mounting holes + indication LED
    [rozhrani_semestralka.kicad_pcb]
2016-05-11 first revision of caseing
    [bottom_part.FCStd, rozhrani_semestralka.kicad_pcb, table_part.FCStd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]
2016-05-12 Just remove one mounting hole
    [rozhrani_semestralka.kicad_pcb]
2016-05-12 Added company logo + dimensions - board 1.0.0B
    [rozhrani_semestralka.kicad_pcb]
2016-05-13 Caseing revise
    [bottom_part.FCStd, table_part.FCStd, top_part.FCStd]
2016-05-25 added capacitor value to buzzer
    [rozhrani_semestralka.sch]
2016-05-28 Edit values of capacitors near tone generator + updated BOM + rename casing folder
    [bottom_part.FCStd, bottom_part.stl, display_bom.xlsx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]
2016-05-29 Updated bom
    [display_bom.xlsx]
2016-05-29 Just generate some files
    [bottom_part.stl, table_part.stl, top_part.stl]
2016-06-20 unconnected central button
    [rozhrani_semestralka.kicad_pcb]
2016-08-10 Just created casing for version 2
    [bottom_part.FCStd, table_part.FCStd, top_part.FCStd]
2016-08-29 newer version added
    [rozhrani_semestralka.sch]
2016-09-22 created version 1.1.0 -- usb connector rotated -- there is no compatible with printed casing, please use version 1.0.0B
    [rozhrani_semestralka.kicad_pcb, rozhrani_semestralka.sch]
2016-10-16 Eddited board to version 1.1.1 - now one of button has choise for 2 colour also added values to silk screen
    [rozhrani_semestralka.kicad_pcb, rozhrani_semestralka.sch]
2017-01-12 Aladin v 1.2.0 pcb - repaired GPIO for /CE and also BUZZERs capacitors, some footprints had change
    [rozhrani_semestralka.kicad_pcb, rozhrani_semestralka.sch]
2017-01-13 Just added fiducials for stencil.
    [rozhrani_semestralka.kicad_pcb]
